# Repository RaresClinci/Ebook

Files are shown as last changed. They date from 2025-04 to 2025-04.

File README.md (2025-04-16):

# Openbook E-Reader

## Schema bloc
``` mermaid
 flowchart TB
    USB1["USB-C"] -->|5V| Charger1["Battery Charger (MCP73832)"]
    Charger1 -->|Charging| LiPo1["LiPo Battery"]
    LiPo1 --> LDO1["3V3 LDO"]
    LiPo1 --> DC5["5V DC/DC"]

    ESP1["ESP32-C3-WROOM"]

    LDO1 -->|3.3V| ESP1
    LDO1 -->|3.3V| Display1["1.5'' E-Ink Display (200x200px)"]
    LDO1 -->|3.3V| SD1["SD Card"]
    LDO1 -->|3.3V| Temp1["Temp/RH Sensor (BME680)"]
    LDO1 -->|3.3V| BatteryGauge["Battery Fuel Gauge (MAX17048)"]
    LDO1 -->|3.3V| Buttons1["Buttons (3x)"]

    ESP1 -- SPI --> Display1
    ESP1 -- SPI --> SD1
    ESP1 -- GPIO --> Buttons1
    ESP1 -- I2C --> Temp1
    ESP1 -- I2C --> BatteryGauge
    ESP1 -- I2C --> RTC["Real Time Clock (DS3231)"]
    ESP1 -- USB --> USB1

```

## Bill of Materials

Pentru componentele care se repeta, am adaugat doar la prima aparitioe datasheetul si linkul catre site.
TP-urile le-am proiectat singur, de aceea nu au o datasheet si un link catre site.

| Name of component  | Device | Check Prices | DataSheet |
|---|---|---|---|
| BOOT_BUTTON | BUTTON_CUSYOMV1 | [Check Price](https://industry.panasonic.com/global/en/products/control/switch/light-touch/number/evqpuj02k)  | [DataSheet](https://industry.panasonic.com/global/en/products/control/switch/light-touch/number/evqpuj02k) |
| C1 | ESP32_WROVER_EAGLE-LTSPICE_CC0402 | [Check Price](https://industry.panasonic.com/global/en/products/control/switch/light-touch/number/evqpuj02k)  | [DataSheet](https://industry.panasonic.com/global/en/products/control/switch/light-touch/number/evqpuj02k) |
| C1_BAT | ESP32_WROVER_EAGLE-LTSPICE_CC0402 | #N/A | #N/A |
| C1_BAT1 | EAGLE-LTSPICE_CC0402 | #N/A | #N/A |
| C1_BAT2 | EAGLE-LTSPICE_CC0402 | #N/A | #N/A |
| C2 | ESP32_WROVER_EAGLE-LTSPICE_CC0402 | #N/A | #N/A |
| C2_BAT | ESP32_WROVER_EAGLE-LTSPICE_CC0402 | #N/A | #N/A |
| C3 | RCL_CPOL-EUCT3528 | #N/A | #N/A |
| C4 | ESP32_WROVER_EAGLE-LTSPICE_CC0402 | #N/A | #N/A |
| C4_USB | ESP32_WROVER_EAGLE-LTSPICE_CC0402 | #N/A | #N/A |
| C5 | ESP32_WROVER_EAGLE-LTSPICE_CC0402 | #N/A | #N/A |
| C5_USB | ESP32_WROVER_EAGLE-LTSPICE_CC0402 | #N/A | #N/A |
| C6 | ESP32_WROVER_EAGLE-LTSPICE_CC0402 | #N/A | #N/A |
| C7 | ESP32_WROVER_EAGLE-LTSPICE_CC0402 | #N/A | #N/A |
| C8 | ESP32_WROVER_EAGLE-LTSPICE_CC0402 | #N/A | #N/A |
| C9 | EAGLE-LTSPICE_CC0402 | #N/A | #N/A |
| C10 | ESP32_WROVER_EAGLE-LTSPICE_CC0402 | #N/A | #N/A |
| C10_SUPERCAP | CPH3225A | [Check Price](https://www.snapeda.com/parts/CPH3225A/Seiko+Instruments/view-part/?ref=eda) | [DataSheet](https://www.snapeda.com/parts/CPH3225A/Seiko+Instruments/view-part/?ref=eda) |
| CHANGE_BUTTON | BUTTON_CUSYOMV1 | [Check Price](https://industry.panasonic.com/global/en/products/control/switch-light-touch/number/evqpuj02k)  | [DataSheet](https://industry.panasonic.com/global/en/products/control/switch-light-touch/number/evqpuj02k) |
| CHG_LED | ADAFRUIT_LEDCHIP-LED0603 | [Check Price](https://www.snapeda.com/parts/KP-1608SURCK/Kingbright/view-part/?ref=search&t=LED%200603) | [DataSheet](https://www.snapeda.com/parts/KP-1608SURCK/Kingbright/view-part/?ref=search&t=LED%200603) |
| C_DELAY | ESP32_WROVER_EAGLE-LTSPICE_CC0402 | #N/A | #N/A |
| D1 | USBLC6-2SC6Y | [Check Price](https://www.snapeda.com/parts/USBLC6-2SC6Y/STMicroelectronics/view-part/?ref=eda) | [DataSheet](https://www.snapeda.com/parts/USBLC6-2SC6Y/STMicroelectronics/view-part/?ref=eda) |
| D2 | ESP32_WROVER_AVX---SD0805S020S1R0_AVX_... | [Check Price](https://eu.mouser.com/ProductDetail/KYOCERA-AVX/SD0805S020S1R0?qs=jCA%252BPfw4LHbpkAoSnwrdjw%3D%3D) | [DataSheet](http://datasheets.avx.com/schottky.pdf) |
| D3 | MBR0530 | [Check Price](https://eu.mouser.com/ProductDetail/KYOCERA-AVX/SD0805S020S1R0?qs=jCA%252BPfw4LHbpkAoSnwrdjw%3D%3D) | [DataSheet](https://eu.mouser.com/ProductDetail/KYOCERA-AVX/SD0805S020S1R0?qs=jCA%252BPfw4LHbpkAoSnwrdjw%3D%3D) |
| D4 | MBR0530 | [Check Price](https://www.snapeda.com/parts/MBR0530/Onsemi/view-part/?ref=eda) | [DataSheet](https://www.snapeda.com/parts/MBR0530/Onsemi/view-part/?ref=eda) |
| D5 | MBR0530 | [Check Price](https://www.snapeda.com/parts/MBR0530/Onsemi/view-part/?ref=eda) | [DataSheet](https://www.snapeda.com/parts/MBR0530/Onsemi/view-part/?ref=eda) |
| D6 | PGB1010603MR | [Check Price](https://www.snapeda.com/parts/PGB1010603MR/Littelfuse/view-part/?ref=eda) | [DataSheet](https://www.snapeda.com/parts/PGB1010603MR/Littelfuse/view-part/?ref=eda) |
| D7 | ESP32_WROVER_AVX---SD0805S020S1R0_AVX_... | [Check Price](https://eu.mouser.com/ProductDetail/KYOCERA-AVX/SD0805S020S1R0?qs=jCA%252BPfw4LHbpkAoSnwrdjw%3D%3D) | [DataSheet](http://datasheets.avx.com/schottky.pdf) |
| D8 | PGB1010603MR | [Check Price](https://www.snapeda.com/parts/PGB1010603MR/Littelfuse/view-part/?ref=eda) | [DataSheet](https://www.snapeda.com/parts/PGB1010603MR/Littelfuse/view-part/?ref=eda) |
| D9 | PGB1010603MR | [Check Price](https://www.snapeda.com/parts/PGB1010603MR/Littelfuse/view-part/?ref=eda) | [DataSheet](https://www.snapeda.com/parts/PGB1010603MR/Littelfuse/view-part/?ref=eda) |
| D10 | PGB1010603MR | [Check Price](https://www.snapeda.com/parts/PGB1010603MR/Littelfuse/view-part/?ref=eda) | [DataSheet](https://www.snapeda.com/parts/PGB1010603MR/Littelfuse/view-part/?ref=eda) |
| D11 | PGB1010603MR | [Check Price](https://www.snapeda.com/parts/PGB1010603MR/Littelfuse/view-part/?ref=eda) | [DataSheet](https://www.snapeda.com/parts/PGB1010603MR/Littelfuse/view-part/?ref=eda) |
| D12 | PGB1010603MR | [Check Price](https://www.snapeda.com/parts/PGB1010603MR/Littelfuse/view-part/?ref=eda) | [DataSheet](https://www.snapeda.com/parts/PGB1010603MR/Littelfuse/view-part/?ref=eda) |
| EPD_C1 | ESP32_WROVER_EAGLE-LTSPICE_CC0402 | #N/A | #N/A |
| EPD_C2 | ESP32_WROVER_EAGLE-LTSPICE_CC0402 | #N/A | #N/A |
| EPD_C5 | ESP32_WROVER_EAGLE-LTSPICE_CC0402 | #N/A | #N/A |
| EPD_C6 | ESP32_WROVER_EAGLE-LTSPICE_CC0402 | #N/A | #N/A |
| EPD_C7 | ESP32_WROVER_EAGLE-LTSPICE_CC0402 | #N/A | #N/A |
| EPD_C8 | ESP32_WROVER_EAGLE-LTSPICE_CC0402 | #N/A | #N/A |
| EPD_C9 | ESP32_WROVER_EAGLE-LTSPICE_CC0402 | #N/A | #N/A |
| EPD_C10 | ESP32_WROVER_EAGLE-LTSPICE_CC0402 | #N/A | #N/A |
| EPD_C11 | ESP32_WROVER_EAGLE-LTSPICE_CC0402 | #N/A | #N/A |
| EPD_C12 | ESP32_WROVER_EAGLE-LTSPICE_CC0402 | #N/A | #N/A |
| IC1 | BD5229G-TR | [Check Price](https://componentsearchengine.com/part-view/BD5229G-TR/ROHM%20Semiconductor) | [DataSheet](https://componentsearchengine.com/part-view/BD5229G-TR/ROHM%20Semiconductor) |
| IC4 | XC6220A331MR-G | [Check Price](https://componentsearchengine.com/part-view/XC6220A331MR-G/Torex) | [DataSheet](https://componentsearchengine.com/part-view/XC6220A331MR-G/Torex) |
| J1 | FH34SRJ-24S-0.5SH_99_ | [Check Price](https://componentsearchengine.com/part-view/XC6220A331MR-G/Torex) | [DataSheet](https://componentsearchengine.com/part-view/XC6220A331MR-G/Torex) |
| J2 | SAMACSYS_PARTS_USB4110-GF-A | [Check Price](https://componentsearchengine.com/part-view/USB4110-GF-A/GCT%20(GLOBAL%20CONNECTOR%20TECHNOLOGY) | [DataSheet](https://componentsearchengine.com/part-view/USB4110-GF-A/GCT%20(GLOBAL%20CONNECTOR%20TECHNOLOGY) |
| J3 | QWIIC_CONNECTORJS-1MM | [Check Price](https://www.snapeda.com/parts/PRT-14417/SparkFun%20Electronics/view-part/?ref=search&t=qwiic%20connectpr) | [Datasheet](https://www.snapeda.com/parts/PRT-14417/SparkFun%20Electronics/view-part/?ref=search&t=qwiic%20connectpr) |
| J4 | 112A-TAAR-R03_ATTEND | [Check Price](https://store.comet.srl.ro/Catalogue/Product/43497/) | [DataSheet](https://store.comet.srl.ro/Catalogue/Product/43497/) |
| L1 | 744043680IND_4828-WE-TPC_WRE | [Check Price](https://eu.mouser.com/ProductDetail/Wurth-Elektronik/744043680?qs=PGXP4M47uW6VkZq%252BkzjrHA%3D%3D) | [DataSheet](https://eu.mouser.com/ProductDetail/Wurth-Elektronik/744043680?qs=PGXP4M47uW6VkZq%252BkzjrHA%3D%3D) |
| PFMF.050.1 | ESP32C6_VARISTORCN1812 | [Check Price](https://www.mouser.co.uk/ProductDetail/EPCOS-TDK/B72520T0350K062?qs=dEfas%2FXlABIszF52uu7vrg%3D%3D) | [DataSheet](https://www.mouser.co.uk/ProductDetail/EPCOS-TDK/B72520T0350K062?qs=dEfas%2FXlABIszF52uu7vrg%3D%3D) |
| Q1 | ESP32_WROVER_SPARKFUN-DISCRETESEMI_MOSFET_... | [Check Price](https://componentsearchengine.com/part-view/DMG2305UX-7/Diodes%20Incorporated) | [DataSheet](https://componentsearchengine.com/part-view/DMG2305UX-7/Diodes%20Incorporated) |
| Q2 | ESP32_WROVER_SPARKFUN-DISCRETESEMI_MOSFET_... | #N/A | #N/A |
| Q3 | D8 | [Check Price](https://componentsearchengine.com/part-view/PGB1010603MR/Littelfuse) | [DataSheet](https://componentsearchengine.com/part-view/PGB1010603MR/Littelfuse) |
| Q4 | Q2_TS-B2_REACHPACK | #N/A | #N/A |
| SJ1 | SJ | [Check Price](https://grabcad.com/library/solder-jumpers-1) | [DataSheet](https://grabcad.com/library/solder-jumpers-1) | |

## Descriere detaliată a funcționalității hardware

### 1. Microcontroller – ESP32-C6
Dispozitivul se bazează pe microcontroller-ul**ESP32-C6-WROOM-1**, bazat pe un nucleu **RISC-V pe 32 de biți**, cu frecvențe de lucru de până la **160 MHz**.

- **Memorie**: 512 KB de SRAM intern și **8 MB flash extern** (W25Q512JVEIQ).
- **Conectivitate**: Wi-Fi 6, Bluetooth 5 LE, USB 2.0
- **Periferice**: suport pentru SPI, I²C, UART și multiple GPIO-uri.
- **Moduri de consum redus**: suportă sleep și deep sleep, ideale pentru dispozitive portabile alimentate cu baterie.

### 2. Afișaj E-Ink
**E-Ink de 7.5" (800x480px)** – Waveshare (sau echivalent) cu rezoluție 800×480

**Interfață**: 4-wire SPI + pini de control (CS, DC, RST, BUSY).  
**Consum**: extrem de redus în regim static; doar în timpul reîmprospătării imaginea consumul crește la ~15–25mA.

 **Avantaj**: Afișajele E-Ink păstrează imaginea fără consum de curent, ceea ce le face perfecte pentru aplicații de tip e-reader.

### 3. Senzor de Mediu – BME680
Senzorul integrează măsurători de **temperatură**, **umiditate**, **presiune atmosferică** și **calitate a aerului (VOC/eCO₂)**.

- **Interfață**: I²C la 400 kHz.
- **Consum**: ~2.1µA în standby, până la câțiva mA în timpul citirilor.

 **BME680** este o alegere excelenta datorita capacitatii sale de a integra multiple tipuri de masuratori intr-un singur cip

### 4. Managementul energiei
- **Baterie Li-Po 3.7V, 2500mAh** – oferă autonomie extinsă.
- **Circuit de încărcare**: MCP73831, conectat la USB-C, permite încărcare cu până la **1A**.
- **Fuel Gauge**: MAX17048 – monitorizează starea bateriei prin I²C (tensiune, încărcare, alertă descărcare).
- **LDO**: XC6220A331MR-G – asigură **tensiune stabilă de 3.3V** pentru toate componentele critice.

### 5. Interacțiune – Butoane (3x)
Dispozitivul include **trei butoane tactile** pentru navigare, selectare și întoarcere pagină. Fiecare este conectat la un GPIO și poate avea debouncing hardware (rezistor + condensator) sau software, pentru evitarea semnalelor false.

### 6. Port USB-C
- **Roluri**: încărcarea bateriei, transfer de date (USB 2.0), și update de firmware (via bootloader sau OTA).
- **Protecție**: ESD (ex: USBLC6-2SC6Y), rezistențe de terminare conforme cu specificațiile USB-C.

### 7. Conector Qwiic (I²C)
Conector standard cu 4 pini (VCC, GND, SDA, SCL) pentru atașarea rapidă a senzorilor/modulor I²C, ideal în extensii și prototipare.

### 8. Card MicroSD(112A-TAAR-R03)
- **Conector dedicat**: pentru log-uri, e-book-uri sau update-uri firmware.
- **Interfață**: Poate fi SD (1-bit / 4-bit) sau SPI, în funcție de configurația firmware-ului.

### 9. Ceas de timp real – RTC DS3231
- **Precizie ridicată**.
- **Backup**: cu baterie sau supercondensator.
- **Comunicare**: I²C, împreună cu ceilalți senzori.

### 10. Memorie Flash externă – W25Q512JVEIQ
- **Interfață**: quad SPI – pentru încărcare rapidă de date și firmware.
- Utilizată pentru stocarea aplicațiilor, imaginilor sau fișierelor mari (ex: e-book-uri).

---

### Interfețele utilizate

| Interfață | Componente conectate |
|---|---|
| **SPI**  | Afișaj E-Ink, memorie flash externă, card SD |
| **I²C**  | BME680, MAX17048 (fuel gauge), RTC DS3231, conector Qwiic |
| **GPIO** | Butoane, control display (RST, BUSY etc.) |
| **USB**  | Alimentare și date (USB-C) |

---

### Estimare consum energetic

| Componentă | Consum tipic |
|---|---|
| ESP32 (activ) | ~80 mA (Wi-Fi) / <10 mA (idle) |
| E-Ink (refresh) | ~15–25 mA |
| BME680 | ~3.6 mA (peak) / 2.1 µA (sleep)  |
| MAX17048 (Fuel Gauge) | ~50 µA |
| DS3231 (RTC) | ~3.5 mA (activ) / <1 µA (backup) |
| Total (deep sleep) | ~50–100 µA |
| Total (activ cu Wi-Fi)  | ~100–150 mA |

> Cu o baterie de **2500mAh**, în regim normal de utilizare (afișaj static, deep sleep majoritatea timpului), autonomia poate atinge **câteva săptămâni**.

## Alocarea pinilor pentru ESP32-C6

| Pin ESP32-C6  | Componentă / Semnal | Descriere |
|---|---|---|
| GPIO1 | I²C SDA (BME680, MAX17048, DS3231, Qwiic) | Linie de date partajată pentru toți senzorii(+ RTC) conectați pe magistrala I²C. |
| GPIO2 | I²C SCL (BME680, MAX17048, DS3231, Qwiic) | Linie de clock pentru sincronizarea comunicației I²C. |
| GPIO5 | SPI MISO (E-Paper) | Recepție date de la afișajul E-Paper. |
| GPIO6 | SPI MOSI (E-Paper) | Transmitere date către afișajul E-Paper. |
| GPIO7 | SPI CLK (E-Paper) | Semnal de clock pentru interfața SPI a ecranului.  |
| GPIO8 | SPI CS (E-Paper) | Chip Select pentru e-paper. |
| GPIO9 | E-Paper DC (Data/Command) | Selectează între transmiterea de date sau comenzi către afișaj. |
| GPIO10 | E-Paper RST | Reset hardware al afișajului. |
| GPIO11 | E-Paper BUSY | Indică dacă afișajul este ocupat cu o operație. |
| GPIO12 | Button #1 | Buton de control (ex. „Pagina următoare”). |
| GPIO13 | Button #2 | Buton de control (ex. „Pagina anterioară”). |
| GPIO14 | Button #3 | Buton de control (ex. „Meniu” sau „Select”). |
| GPIO15 | MAX17048 ALERT (opțional) | Semnal de alertă de la senzorul de baterie (low battery). |
| GPIO16 | USB D+ (intern la USB PHY) | Semnal diferențial pozitiv pentru conexiunea USB 2.0. |
| GPIO17 | USB D- (intern la USB PHY) | Semnal diferențial negativ pentru conexiunea USB 2.0. |
| GPIO18 | LED de status (opțional) | LED pentru semnalizare stări (Wi-Fi, încărcare etc.). |
| GPIO19 | SD Card CS (opțional) | Chip Select pentru cardul microSD (SPI). |
| GPIO20 | SD Card MISO (opțional) | Linie de citire date de la cardul microSD. |
| GPIO21 | SD Card MOSI (opțional) | Linie de scriere date către cardul microSD. |
| GPIO4 | SD Card CLK (opțional) | Linie de clock pentru comunicația SPI cu cardul SD.|

## Note
- am adaugat la partea de PCB 2D niste masuratori in plus pentru claritate
- am pozitionat TP-urile in cel mai apropiat loc de componentele conectate
- am mai adaugat pe placa o zona unde poate fi scris numarul de serie al placii si versiunea ei(probabil va deveni Openbook v1.2 dupa feedback - UPDATE: chiar a devenit)
- pentru baterie, am folosit un paralelipiped cu dimensiunile maxime din datasheet
- la partea de PCB, am aprobat 2 erori de gauri de la o componenta si o eroare de Airwire la componenta J4, are 9 grounduri puse intr-un grid 3x3 si cel din mijloc nu e accesibil

## Concluzii
A fost un proiect destul de solicitant, dar cu multa munca am reusit sa il duc pana la capat. Am luat in considerare majoritatea indicatiilor si sunt deschis sa fac imbunatatiri pe urma feedbackului.

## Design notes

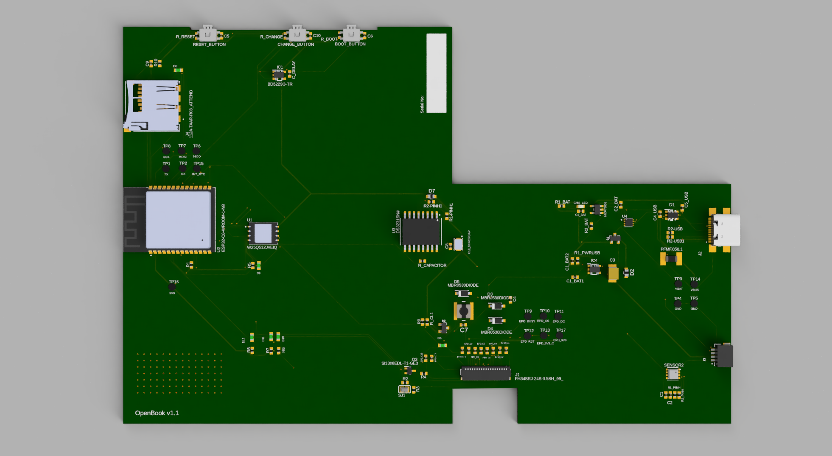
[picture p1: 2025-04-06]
Images/PCB_Openbook_3D_2025-Apr-06_12-04-20PM-000_CustomizedView25513308225.png

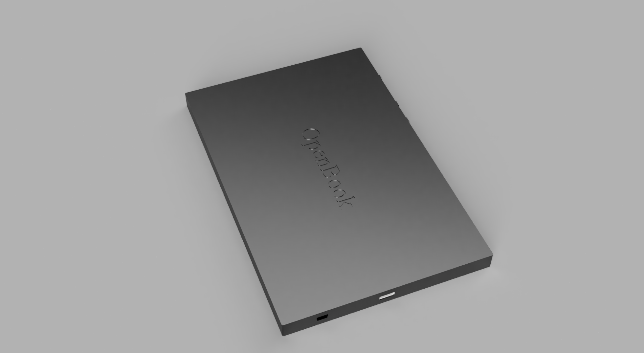
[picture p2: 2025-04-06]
Images/OpenBook_Enclosure_2025-Apr-06_12-09-38PM-000_CustomizedView32989049205.png

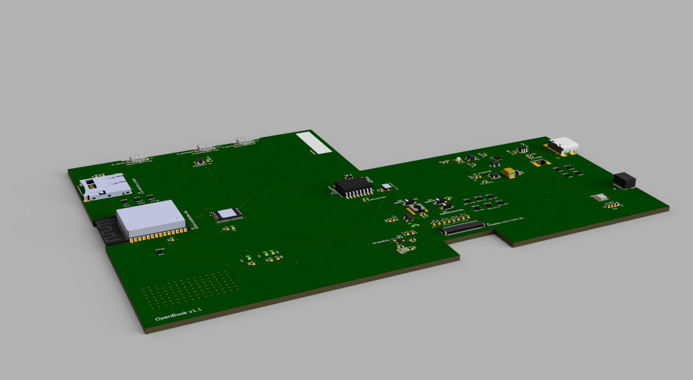
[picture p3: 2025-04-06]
Images/PCB_Openbook_3D_2025-Apr-06_12-02-53PM-000_CustomizedView3641258684.png

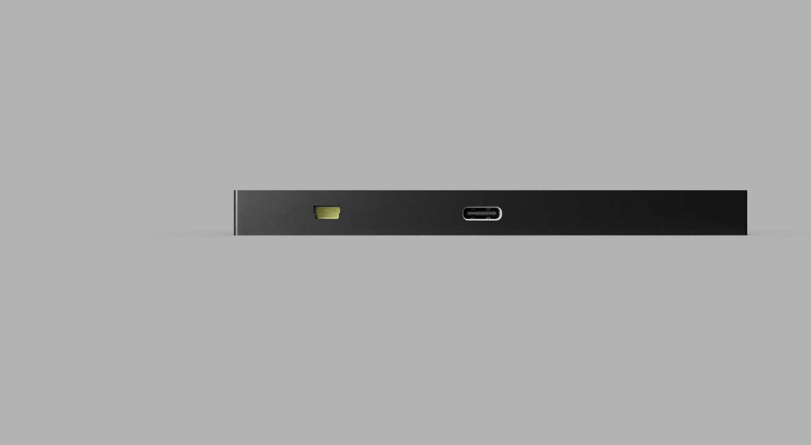
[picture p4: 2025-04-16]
Images/OpenBook_Enclosure_2025-Apr-16_10-03-07AM-000_CustomizedView7075589105.png

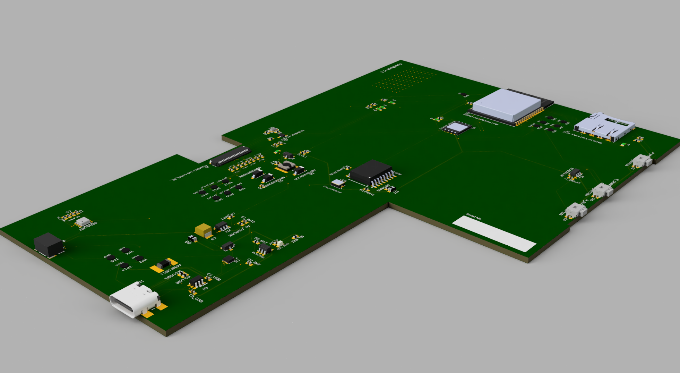
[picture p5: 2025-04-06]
Images/PCB_Openbook_3D_2025-Apr-06_12-05-02PM-000_CustomizedView13622716074.png

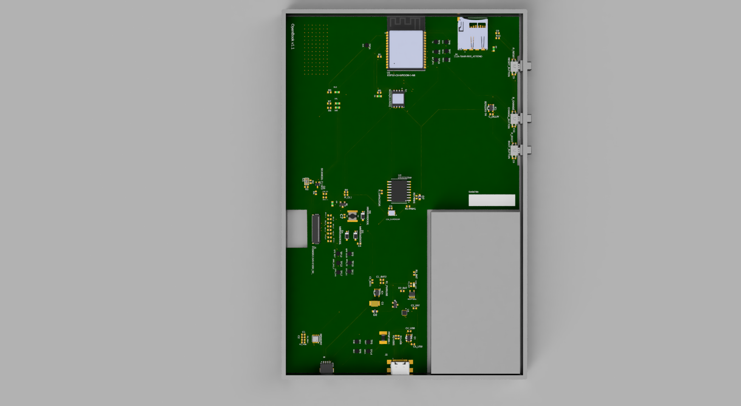
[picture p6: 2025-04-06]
Images/b6aed16a-0078-495b-a1fc-863c3d2823d8.PNG

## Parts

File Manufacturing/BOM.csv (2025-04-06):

Qty | Value | Device | Package | Parts | Description | ARROW_PART_NUMBER | ARROW_PRICE-STOCK | AVAILABILITY | CENTROID_NOT_SPECIFIED | CHECK_PRICES | COPYRIGHT | DATASHEET | DESCRIPTION | DIGIKEY_DESCRIPTION | DIGIKEY_PART_NUMBER | HEIGHT | LEAD_FREE | MANUFACTURER_NAME | MANUFACTURER_PART_NUMBER | MF | MFR_NAME | MOUSER_PART_NUMBER | MOUSER_PRICE-STOCK | MOUSER_TESTING_PART_NUMBER | MOUSER_TESTING_PRICE-STOCK | MP | MPN | PACKAGE | POPULARITY | PREFIX | PRICE | PROD_ID | PURCHASE-URL | ROHS | SNAPEDA_LINK | SPICEPREFIX | TEMPERATURE_RANGE_HIGH | TEMPERATURE_RANGE_LOW | VALUE
1 |  | ADAFRUIT_LEDCHIP-LED0603 | ADAFRUIT_CHIP-LED0603 | CHG_LED | LED
1 |  | SJ | SJ | SJ1 | SMD solder JUMPER |  |  |  |  |  |  |  |  |  |  |  |  |  |  |  |  |  |  |  |  |  |  |  | 3
1 | 0.1uF/50V | ESP32_WROVER_EAGLE-LTSPICE_CC0402 | EAGLE-LTSPICE_C0402 | EPD_C5 | CAPACITOR, European symbol
1 | 0.47 | ESP32_WROVER_EAGLE-LTSPICE_RR0402 | ESP32_WROVER_EAGLE-LTSPICE_R0402 | R3 | RESISTOR, European symbol
1 | 100K | ESP32_WROVER_EAGLE-LTSPICE_RR0402 | ESP32_WROVER_EAGLE-LTSPICE_R0402 | R1_PWRUSB | RESISTOR, European symbol
8 | 100nF | ESP32_WROVER_EAGLE-LTSPICE_CC0402 | EAGLE-LTSPICE_C0402 | C1, C2, C4_USB, C6, C8, C9, C10, C_DELAY | CAPACITOR, European symbol
1 | 100uF TANT | RCL_CPOL-EUCT3528 | RCL_CT3528 | C3 | POLARIZED CAPACITOR, European symbol |  |  |  |  |  |  |  |  |  |  |  |  |  |  |  |  |  |  |  |  |  |  |  | 0 |  |  |  |  |  |  | C
16 | 10K | ESP32_WROVER_EAGLE-LTSPICE_RR0402 | ESP32_WROVER_EAGLE-LTSPICE_R0402 | R1, R1-PINH1, R1_PINH, R2-PINH1, R2_PINH, R4, R5, R6, R7, R8, R9, R10, R_BOOT, R_CHANGE, R_CL1, R_RESET | RESISTOR, European symbol
1 | 10uF | ESP32_WROVER_EAGLE-LTSPICE_CC0402 | EAGLE-LTSPICE_C0402 | C7 | CAPACITOR, European symbol
1 | 112A-TAAR-R03_ATTEND | 112A-TAAR-R03_ATTEND | 112ATAARR03ATTEND | J4 | Micro SD Card Socket, Push-Push Type, Top Mount, SMT, H=1.83mm, 10u |  |  |  |  |  |  |  | Micro SD Card Socket | Push-Push Type | Top Mount | SMT | H=1.83mm | 10u |  |  | 1.9mm |  | ATTEND | 112A-TAAR-R03 ATTEND
1 | 15 | ESP32_WROVER_EAGLE-LTSPICE_RR0402 | ESP32_WROVER_EAGLE-LTSPICE_R0402 | R_CAPACITOR | RESISTOR, European symbol
1 | 1uF | ESP32_WROVER_EAGLE-LTSPICE_CC0402 | EAGLE-LTSPICE_C0402 | C5 | CAPACITOR, European symbol
9 | 1uF/50V | ESP32_WROVER_EAGLE-LTSPICE_CC0402 | EAGLE-LTSPICE_C0402 | EPD_C1, EPD_C2, EPD_C6, EPD_C7, EPD_C8, EPD_C9, EPD_C10, EPD_C11, EPD_C12 | CAPACITOR, European symbol
1 | 2.2 | ESP32_WROVER_EAGLE-LTSPICE_RR0402 | ESP32_WROVER_EAGLE-LTSPICE_R0402 | R2 | RESISTOR, European symbol
1 | 200 | ESP32_WROVER_EAGLE-LTSPICE_RR0402 | ESP32_WROVER_EAGLE-LTSPICE_R0402 | R1_BAT | RESISTOR, European symbol
2 | 20V/4.2A/52mO/1.4W | ESP32_WROVER_SPARKFUN-DISCRETESEMI_MOSFET_PCH-DMG2305UX-7 | ESP32_WROVER_SPARKFUN-DISCRETESEMI_SOT23-3 | Q1, Q2 | P-channel MOSFETs
1 | 2K | ESP32_WROVER_EAGLE-LTSPICE_RR0402 | ESP32_WROVER_EAGLE-LTSPICE_R0402 | R2_BAT | RESISTOR, European symbol
5 | 4.7uF | ESP32_WROVER_EAGLE-LTSPICE_CC0402 | EAGLE-LTSPICE_C0402 | C1_BAT, C1_BAT1, C1_BAT2, C2_BAT, C5_USB | CAPACITOR, European symbol
1 | 4.7uF/25V | ESP32_WROVER_EAGLE-LTSPICE_CC0402 | EAGLE-LTSPICE_C0402 | C4 | CAPACITOR, European symbol
2 | 5k1 | ESP32_WROVER_EAGLE-LTSPICE_RR0402 | ESP32_WROVER_EAGLE-LTSPICE_R0402 | R2-USB, R2-USB1 | RESISTOR, European symbol
1 | 68uH | 744043680IND_4828-WE-TPC_WRE | IND_4828-WE-TPC_WRE | L1 |  |  |  |  |  |  | Copyright (C) 2024 Ultra Librarian. All rights reserved. |  |  |  |  |  |  |  | 744043680 |  | Wurth Electronics
1 | BD5229G-TR | BD5229G-TR | SOT95P280X125-5N | IC1 | Voltage Detector with Adjustable Delay Time: CMOS processes are utilized to develop high precision, low current consumption CMOS reset ICs that allow arbitrary setting of the delay time. The extensive lineup includes both Nch Open Drain and CMOS output types in a wide range of detection voltages (from 2.3V to 6.0V, in 0.1V steps), enabling selection of the ideal solution based on customer requirements. In addition, the entire series is of course both lead-free and RoHS-compliant. |  |  |  |  |  |  |  | Voltage Detector with Adjustable Delay Time: CMOS processes are utilized to develop high precision | low current consumption CMOS reset ICs that allow arbitrary setting of the delay time. The extensive lineup includes both Nch Open Drain and CMOS output types in a wide range of detection voltages (from 2.3V to 6.0V | in 0.1V steps) | enabling selection of the ideal solution based on customer requirements. In addition | the entire series is of course both lead-free and RoHS-compliant. |  |  | 1.25mm |  | ROHM Semiconductor | BD5229G-TR |  |  | 755-BD5229G-TR | https://www.mouser.co.uk/ProductDetail/ROHM-Semiconductor/BD5229G-TR?qs=4kLU8WoGk0vvnhrrYwdszw%3D%3D
1 | BME688 | ESP32_WROVER_BME680_BME680 | ESP32_WROVER_BME680_PSON80P300X300X100-8N | SENSOR2 | Integrated Environmental Unit |  |  | Unavailable |  |  |  |  | Integrated Environmental Unit |  |  |  |  |  |  | Bosch Sensortec |  |  |  |  |  | BME680 |  | LGA-8 Bosch Tools |  |  | None
3 | BUTTON_CUSYOMV1BUTTON | BUTTON_CUSYOMV1BUTTON | MYBUTTON | BOOT_BUTTON, CHANGE_BUTTON, RESET_BUTTON
1 | CPH3225A | CPH3225A | CAPCP3225X100N | C10_SUPERCAP | Cap 0.011F 3.3V 1210 Flat Check availability |  |  | Not in stock |  | https://www.snapeda.com/parts/CPH3225A/Seiko+Instruments/view-part/?ref=eda |  |  | 11 mF (EDLC) Supercapacitor 3.3 V 1210 (3225 Metric) - - |  |  |  |  |  |  | Seiko Instruments |  |  |  |  |  | CPH3225A |  | 1210 Seiko |  |  | None |  | https://www.snapeda.com/api/url_track_click_mouser/?unipart_id=562593&manufacturer=Seiko Instruments&part_name=CPH3225A&search_term=None |  | https://www.snapeda.com/parts/CPH3225A/Seiko+Instruments/view-part/?ref=snap
1 | DS3231SN# | DS3231SN# | SOIC127P1032X265-16N | U3 | Real Time Clock Serial 16-Pin SOIC W T/R Check availability |  |  | In Stock |  | https://www.snapeda.com/parts/DS3231SN%23/Analog+Devices/view-part/?ref=eda |  |  | Extremely Accurate I²C-Integrated RTC/TCXO/Crystal |  |  |  |  |  |  | Analog Devices |  |  |  |  |  | DS3231SN# |  | SOIC-16 Maxim |  |  | None |  | https://www.snapeda.com/api/url_track_click_mouser/?unipart_id=99048&manufacturer=Analog Devices&part_name=DS3231SN#&search_term=None |  | https://www.snapeda.com/parts/DS3231SN%23/Analog+Devices/view-part/?ref=snap
1 | ESP32-C6-WROOM-1-N8 | ESP32-C6-WROOM-1-N8 | XCVR_ESP32-C6-WROOM-1-N8 | U2 | Check availability |  |  | In Stock |  | https://www.snapeda.com/parts/ESP32-C6-WROOM-1-N8/Espressif+Systems/view-part/?ref=eda |  |  | Multiprotocol Modules ESP32-C6 module | Wi-Fi 6 in 2.4 GHz band | Bluetooth 5 | Zigbee 3.0 and Thread. ESP34-WROOM Compatible - ENGINEERING SAMPLE |  |  |  |  |  |  | Espressif Systems |  |  |  |  |  | ESP32-C6-WROOM-1-N8 |  | None |  |  | None |  |  |  | https://www.snapeda.com/parts/ESP32-C6-WROOM-1-N8/Espressif+Systems/view-part/?ref=snap
1 | ESP32C6_VARISTORCN1812 | ESP32C6_VARISTORCN1812 | ESP32C6_VARISTOR_CT/CN1812 | PFMF.050.1 | VARISTOR |  |  |  |  |  |  |  |  |  |  |  |  |  |  |  |  |  |  |  |  |  |  |  | 0
1 | ESP32_WROVER_SPARKFUN-IC-POWER_MCP73831 | ESP32_WROVER_SPARKFUN-IC-POWER_MCP73831 | ESP32_WROVER_SPARKFUN-IC-POWER_SOT23-5 | MCP73831 | MCP73831T Li-Ion, Li-Pol Controller |  |  |  |  |  |  |  |  |  |  |  |  |  |  |  |  |  |  |  |  |  |  |  |  |  |  | IC-09995
1 | FH34SRJ-24S-0.5SH_99_ | FH34SRJ-24S-0.5SH_99_ | FH34SRJ24S05SH99 | J1 | (0.50mm) Surface Mount, Right Angle |  |  |  |  |  |  |  | 24 Position FFC | FPC Connector Contacts | (0.50mm) Surface Mount | Right Angle |  |  | 1.1mm |  | Hirose | FH34SRJ-24S-0.5SH(99) |  |  | 798-FH34SRJ24S05SH99 | https://www.mouser.co.uk/ProductDetail/Hirose-Connector/FH34SRJ-24S-0.5SH99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
1 | MAX17048G+T10 | MAX17048G+T10 | SON50P200X200X80-9N | U4 | Check availability |  |  | In Stock |  | https://www.snapeda.com/parts/MAX17048G+T10/Analog+Devices/view-part/?ref=eda |  |  | 3µA 1-Cell/2-Cell Fuel Gauge with ModelGauge |  |  |  |  |  |  | Analog Devices |  |  |  |  |  | MAX17048G+T10 |  | TDFN-8 Maxim |  |  | None |  | https://www.snapeda.com/api/url_track_click_mouser/?unipart_id=329239&manufacturer=Analog Devices&part_name=MAX17048G+T10&search_term=None |  | https://www.snapeda.com/parts/MAX17048G+T10/Analog+Devices/view-part/?ref=snap
3 | MBR0530DIODE | MBR0530DIODE | SOD3716X135N | D3, D4, D5 | ON SEMICONDUCTOR - MBR0530 - DIODE, SCHOTTKY, 0.5A, 30V, SOD-123
6 | PGB1010603MRDIODE | PGB1010603MRDIODE | DIOC1608X36N | D6, D8, D9, D10, D11, D12 | Check availability
1 | QWIIC_RIGHT_ANGLE | QWIIC_CONNECTORJS-1MM | JST04_1MM_RA | J3 | SparkFun I2C Standard Qwiic Connector |  |  |  |  |  |  |  |  |  |  |  |  |  |  |  |  |  |  |  |  |  |  |  |  |  |  | CONN-13694 |  |  |  |  |  |  | QWIIC_RIGHT_ANGLE
1 | SAMACSYS_PARTS_USB4110-GF-A | SAMACSYS_PARTS_USB4110-GF-A | SAMACSYS_PARTS_USB4110GFA | J2 | CONN USB 2.0 TYPE-C R/A SMT |  |  |  |  |  |  |  | CONN USB 2.0 TYPE-C R/A SMT |  |  | 3.26mm |  | GCT (GLOBAL CONNECTOR TECHNOLOGY) | USB4110-GF-A |  |  | 640-USB4110-GF-A | https://www.mouser.co.uk/ProductDetail/GCT/USB4110-GF-A?qs=KUoIvG%2F9IlYiZvIXQjyJeA%3D%3D
2 | SD0805S020S1R0 | ESP32_WROVER_AVX---SD0805S020S1R0_AVX_SD0805S020S1R0_0_0AVX_SD0805S020S1R0_0_0 | ESP32_WROVER_AVX---SD0805S020S1R0_AVX_SD0805S020S1R0_0 | D2, D7 | Schottky Barrier Rectifier Diode |  |  |  | No |  |  | http://datasheets.avx.com/schottky.pdf |  | DIODE SCHOTTKY 20V 1A 0805 | 478-7800-1-ND |  | yes |  |  | AVX |  | 581-SD0805S020S1R0 |  |  |  |  |  | 0805 (2012 metric) |  | D |  |  |  | yes |  |  | +125°C | -55°C
1 | SI1308EDL-T1-GE3 | SI1308EDL-T1-GE3 | SOT65P210X110-3N | Q3 | MOSFET N-Ch 30V 1.5A TrenchFET SC70 Vishay Si1308EDL-T1-GE3 N-channel MOSFET Transistor, 1.5 A, 30 V, 3-Pin SC-70 |  |  | In Stock |  | https://www.snapeda.com/parts/SI1308EDL-T1-GE3/Vishay+Siliconix/view-part/?ref=eda |  |  | Si1308EDL-T1-GE3 N-channel MOSFET Transistor | 1.5 A | 30 V | 3-Pin SC-70 | Siliconix / Vishay SI1308EDL-T1-GE3 |  |  |  |  |  |  | Vishay Siliconix |  |  |  |  |  | SI1308EDL-T1-GE3 |  | SOT-323 Vishay Semiconductor |  |  | None |  | https://www.snapeda.com/api/url_track_click_mouser/?unipart_id=274603&manufacturer=Vishay Siliconix&part_name=SI1308EDL-T1-GE3&search_term=None |  | https://www.snapeda.com/parts/SI1308EDL-T1-GE3/Vishay+Siliconix/view-part/?ref=snap
17 | TPTP20R | TPTP20R | TP20R | TP1, TP2, TP3, TP4, TP5, TP6, TP7, TP8, TP9, TP10, TP11, TP12, TP13, TP14, TP15, TP16, TP17 | Test pad
1 | USBLC6-2SC6Y | USBLC6-2SC6Y | SOT95P280X145-6N | D1 | Low Cap. ESD Protection Auto SOT-23-6 STMicroelectronics USBLC6-2SC6Y, Dual Uni-Directional TVS Diode Array, 6-Pin SOT-23 |  |  | In Stock |  | https://www.snapeda.com/parts/USBLC6-2SC6Y/STMicroelectronics/view-part/?ref=eda |  |  | 17V Clamp 5A (8/20µs) Ipp Tvs Diode Surface Mount SOT-23-6 |  |  |  |  |  |  | STMicroelectronics |  |  |  |  |  | USBLC6-2SC6Y |  | SOT-23-6 STMicroelectronics |  |  | None |  |  |  | https://www.snapeda.com/parts/USBLC6-2SC6Y/STMicroelectronics/view-part/?ref=snap
1 | W25Q512JVEIQ | W25Q512JVEIQ | SON127P600X800X80-9N | U1 | Check availability |  |  | In Stock |  | https://www.snapeda.com/parts/W25Q512JVEIQ/Winbond+Electronics/view-part/?ref=eda |  |  | FLASH - NOR Memory IC 512Mb (64M x 8) SPI - Quad I/O 133 MHz 8-WSON (8x6) |  |  |  |  |  |  | Winbond Electronics |  |  |  |  |  | W25Q512JVEIQ |  | Package |  |  | None |  |  |  | https://www.snapeda.com/parts/W25Q512JVEIQ/Winbond+Electronics/view-part/?ref=snap
1 | XC6220A331MR-G | XC6220A331MR-G | SOT95P280X120-5N | IC4 | LDO Voltage Regulators |  |  |  |  |  |  |  | LDO Voltage Regulators |  |  | 1.2mm |  | Torex | XC6220A331MR-G |  |  | 865-XC6220A331MR-G | https://www.mouser.co.uk/ProductDetail/Torex-Semiconductor/XC6220A331MR-G?qs=AsjdqWjXhJ8ZSWznL1J0gg%3D%3D

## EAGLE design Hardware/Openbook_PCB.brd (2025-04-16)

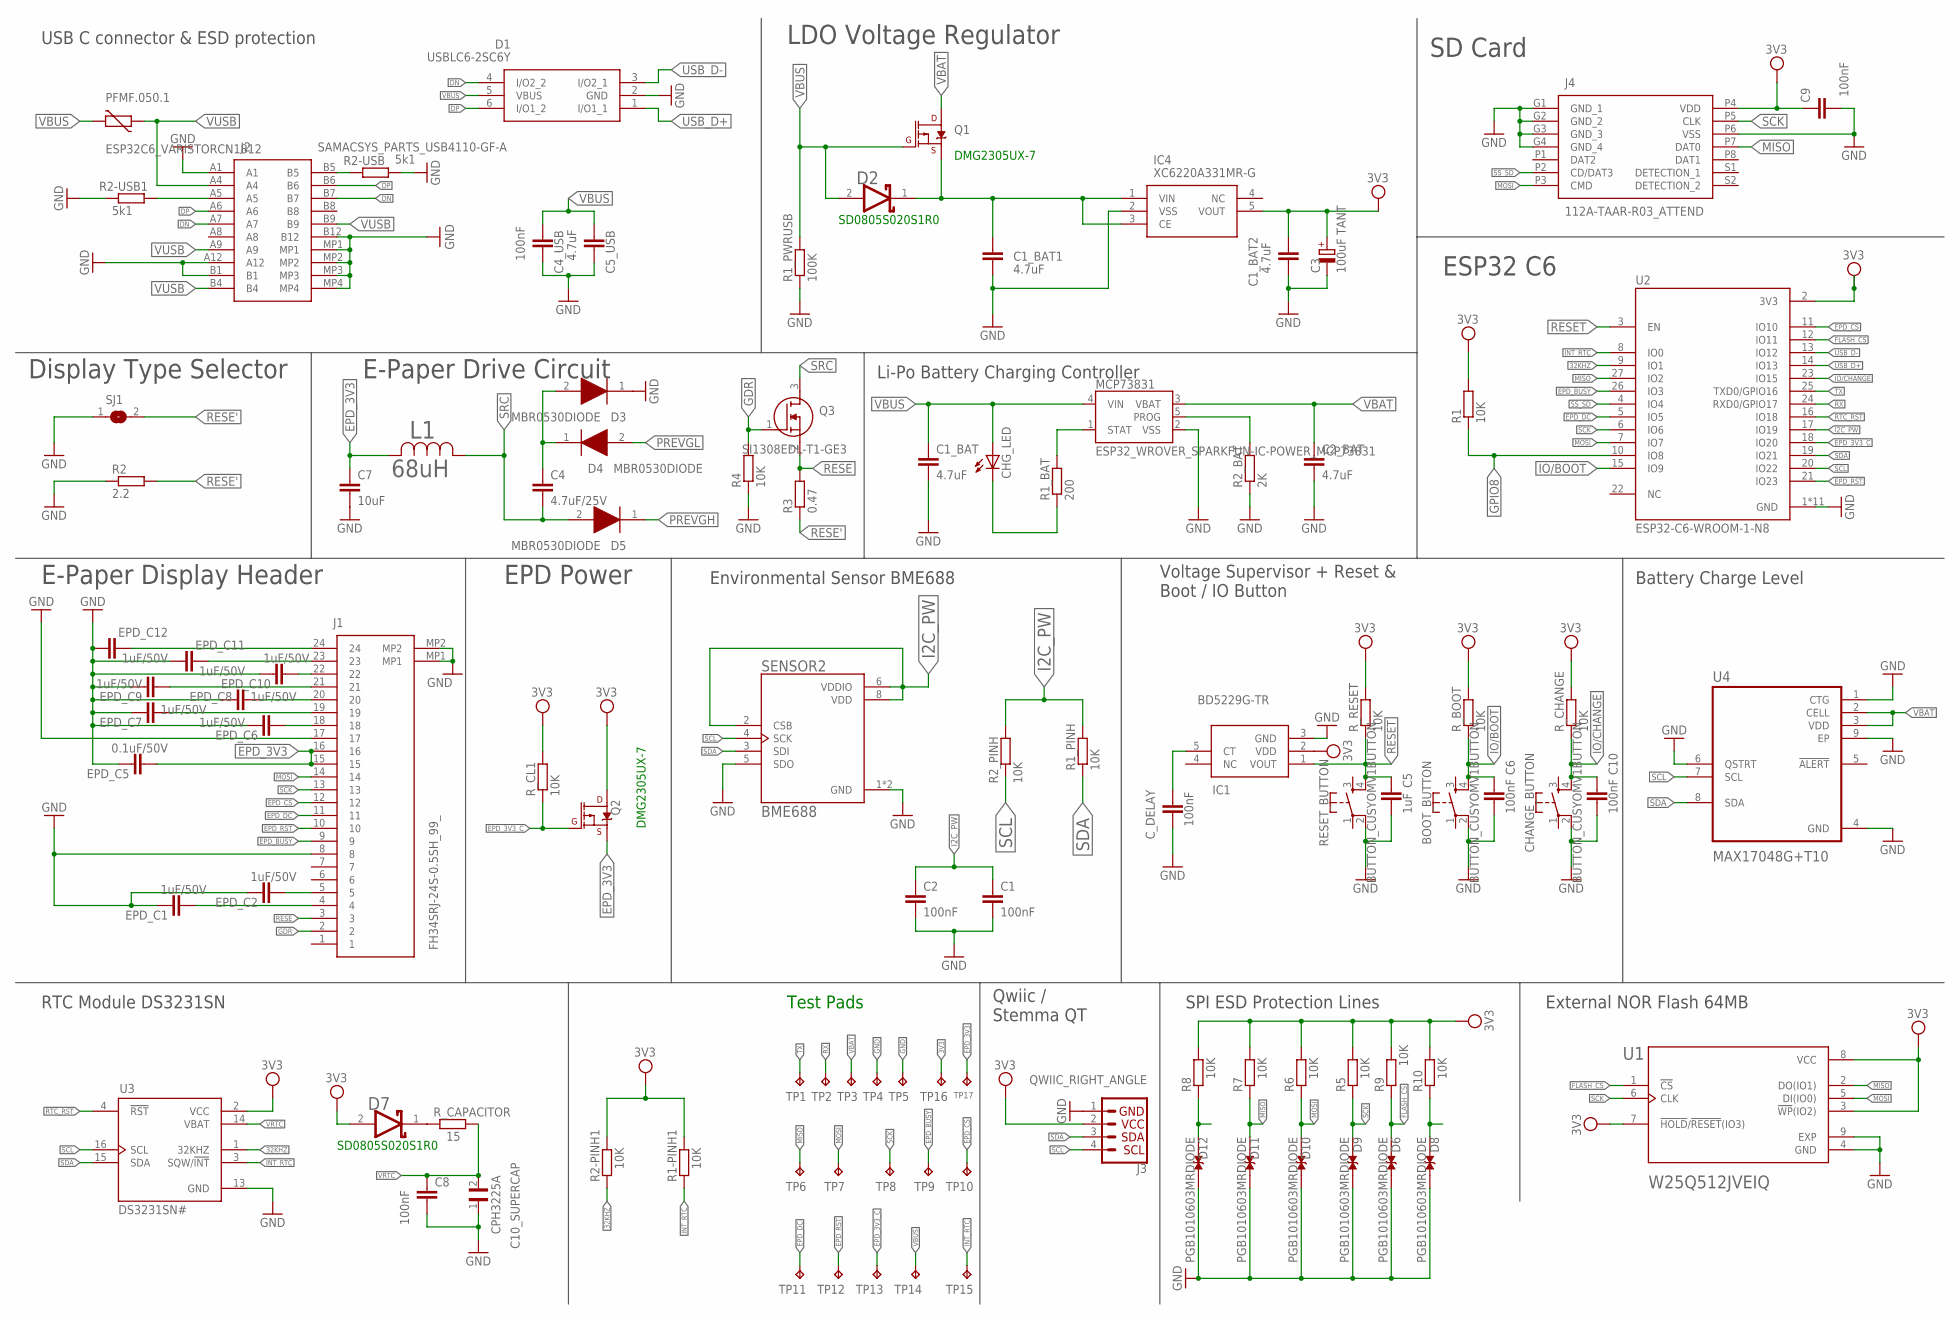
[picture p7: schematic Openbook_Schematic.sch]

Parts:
BOOT_BUTTON: BUTTON_CUSYOMV1BUTTON; MYBUTTON
C1, C2, C4_USB, C6, C8, C9, C10: 100nF; EAGLE-LTSPICE_C0402
C1_BAT, C1_BAT1, C1_BAT2, C2_BAT, C5_USB: 4.7uF; EAGLE-LTSPICE_C0402
C3: 100uF TANT; RCL_CT3528
C4: 4.7uF/25V; EAGLE-LTSPICE_C0402
C5: 1uF; EAGLE-LTSPICE_C0402
C7: 10uF; EAGLE-LTSPICE_C0402
C10_SUPERCAP: CPH3225A; CAPCP3225X100N
CHANGE_BUTTON: BUTTON_CUSYOMV1BUTTON; MYBUTTON
CHG_LED: ADAFRUIT_LEDCHIP-LED0603; ADAFRUIT_CHIP-LED0603
C_DELAY: 100nF; EAGLE-LTSPICE_C0402
D1: USBLC6-2SC6Y; SOT95P280X145-6N
D2, D7: SD0805S020S1R0; ESP32_WROVER_AVX---SD0805S020S1R0_AVX_SD0805S020S1R0_0
D3, D4, D5: MBR0530DIODE; SOD3716X135N
D6, D8, D9, D10, D11, D12: PGB1010603MRDIODE; DIOC1608X36N
EPD_C1, EPD_C2, EPD_C6, EPD_C7, EPD_C8, EPD_C9, EPD_C10, EPD_C11, EPD_C12: 1uF/50V; EAGLE-LTSPICE_C0402
EPD_C5: 0.1uF/50V; EAGLE-LTSPICE_C0402
IC1: BD5229G-TR; SOT95P280X125-5N
IC4: XC6220A331MR-G; SOT95P280X120-5N
J1: FH34SRJ-24S-0.5SH_99_; FH34SRJ24S05SH99
J2: SAMACSYS_PARTS_USB4110-GF-A; SAMACSYS_PARTS_USB4110GFA
J3: QWIIC_RIGHT_ANGLE; JST04_1MM_RA
J4: 112A-TAAR-R03_ATTEND; 112ATAARR03ATTEND
L1: 68uH; IND_4828-WE-TPC_WRE
MCP73831: ESP32_WROVER_SPARKFUN-IC-POWER_MCP73831; ESP32_WROVER_SPARKFUN-IC-POWER_SOT23-5
PFMF.050.1: ESP32C6_VARISTORCN1812; ESP32C6_VARISTOR_CT/CN1812
Q1, Q2: 20V/4.2A/52mΩ/1.4W; ESP32_WROVER_SPARKFUN-DISCRETESEMI_SOT23-3
Q3: SI1308EDL-T1-GE3; SOT65P210X110-3N
R1, R1-PINH1, R1_PINH, R2-PINH1, R2_PINH, R4, R5, R6, R7, R8, R9, R10: 10K; ESP32_WROVER_EAGLE-LTSPICE_R0402
R1_BAT: 200; ESP32_WROVER_EAGLE-LTSPICE_R0402
R1_PWRUSB: 100K; ESP32_WROVER_EAGLE-LTSPICE_R0402
R2: 2.2; ESP32_WROVER_EAGLE-LTSPICE_R0402
R2-USB, R2-USB1: 5k1; ESP32_WROVER_EAGLE-LTSPICE_R0402
R2_BAT: 2K; ESP32_WROVER_EAGLE-LTSPICE_R0402
R3: 0.47; ESP32_WROVER_EAGLE-LTSPICE_R0402
RESET_BUTTON: BUTTON_CUSYOMV1BUTTON; MYBUTTON
R_BOOT: 10K; ESP32_WROVER_EAGLE-LTSPICE_R0402
R_CAPACITOR: 15; ESP32_WROVER_EAGLE-LTSPICE_R0402
R_CHANGE: 10K; ESP32_WROVER_EAGLE-LTSPICE_R0402
R_CL1: 10K; ESP32_WROVER_EAGLE-LTSPICE_R0402
R_RESET: 10K; ESP32_WROVER_EAGLE-LTSPICE_R0402
SENSOR2: BME688; ESP32_WROVER_BME680_PSON80P300X300X100-8N
SJ1: SJ
TP1, TP2, TP3, TP4, TP5, TP6, TP7, TP8, TP9, TP10, TP11, TP12, TP13, TP14, TP15, TP16, TP17: TPTP20R; TP20R
U1: W25Q512JVEIQ; SON127P600X800X80-9N
U2: ESP32-C6-WROOM-1-N8; XCVR_ESP32-C6-WROOM-1-N8
U3: DS3231SN#; SOIC127P1032X265-16N
U4: MAX17048G+T10; SON50P200X200X80-9N

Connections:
3V3: C1_BAT2.1, C3.+, C9.1, D7.2 (ANODE), IC1.2 (VDD), IC4.5 (VOUT), J3.2, J4.P4 (VDD), Q2.3 (D), R1.2, R1-PINH1.2, R2-PINH1.2, R5.2, R6.2, R7.2, R8.2, R9.2, R10.2, R_BOOT.2, R_CHANGE.2, R_CL1.2, R_RESET.2, TP16.TP, U1.3 (!WP!(IO2)), U1.7 (!HOLD!/!RESET!(IO3)), U1.8 (VCC), U2.2 (3V3), U3.2 (VCC)
32KHZ: R2-PINH1.1, U2.9 (IO1), U3.1 (32KHZ)
DN: D1.4 (I/O2_2), J2.A7, J2.B7
DP: D1.6 (I/O1_2), J2.A6, J2.B6
EPD_3V3: C7.1, EPD_C5.2, J1.15, J1.16, L1.2, Q2.2 (S), TP17.TP
EPD_3V3_C: Q2.1 (G), R_CL1.1, TP13.TP, U2.18 (IO20)
EPD_BUSY: J1.9, TP9.TP, U2.26 (IO3)
EPD_CS: J1.12, TP10.TP, U2.11 (IO10)
EPD_DC: J1.11, TP11.TP, U2.5 (IO5)
EPD_RST: J1.10, TP12.TP, U2.21 (IO23)
FLASH_CS: D6.1, R9.1, U1.1 (!CS), U2.12 (IO11)
GDR: J1.2, Q3.1 (G), R4.2
GND: BOOT_BUTTON.2, C1.2, C1_BAT.2, C1_BAT1.2, C1_BAT2.2, C2.2, C2_BAT.2, C3.-, C4_USB.2, C5.2, C5_USB.2, C6.2, C7.2, C8.2, C9.2, C10.2, C10_SUPERCAP.1, CHANGE_BUTTON.2, C_DELAY.2, D1.2 (GND), D3.1 (K), D6.2, D8.2, D9.2, D10.2, D11.2, D12.2, EPD_C1.1, EPD_C2.1, EPD_C5.1, EPD_C6.1, EPD_C7.1, EPD_C8.1, EPD_C9.1, EPD_C10.1, EPD_C11.1, EPD_C12.1, IC1.3 (GND), IC4.2 (VSS), J1.8, J1.17, J1.MP1, J1.MP2, J2.A1, J2.A12, J2.B1, J2.B12, J2.MP1, J2.MP2, J2.MP3, J2.MP4, J3.1, J4.G1 (GND_1), J4.G2 (GND_2), J4.G3 (GND_3), J4.G4 (GND_4), J4.P6 (VSS), MCP73831.2 (VSS), R1_PWRUSB.1, R2.1, R2-USB.2, R2-USB1.1, R2_BAT.1, R4.1, RESET_BUTTON.2, SENSOR2.1 (GND), SENSOR2.5 (SDO), SENSOR2.7 (GND), SJ1.1, TP4.TP, TP5.TP, U1.4 (GND), U1.9 (EXP), U2.1 (GND), U2.28 (GND), U2.29_1 (GND), U2.29_2 (GND), U2.29_3 (GND), U2.29_4 (GND), U2.29_5 (GND), U2.29_6 (GND), U2.29_7 (GND), U2.29_8 (GND), U2.29_9 (GND), U3.13 (GND), U4.1 (CTG), U4.4 (GND), U4.6 (QSTRT), U4.9 (EP)
GPIO8: R1.1, U2.10 (IO8)
I2C_PW: C1.1, C2.1, R1_PINH.2, R2_PINH.2, SENSOR2.2 (CSB), SENSOR2.6 (VDDIO), SENSOR2.8 (VDD), U2.17 (IO19)
INT_RTC: R1-PINH1.1, TP15.TP, U2.8 (IO0), U3.3 (SQW/!INT)
IO/BOOT: BOOT_BUTTON.4, C6.1, R_BOOT.1, U2.15 (IO9)
IO/CHANGE: C10.1, CHANGE_BUTTON.4, R_CHANGE.1, U2.23 (IO15)
MISO: D11.1, J4.P7 (DAT0), R7.1, TP6.TP, U1.2 (DO(IO1)), U2.27 (IO2)
MOSI: D10.1, J1.14, J4.P3 (CMD), R6.1, TP7.TP, U1.5 (DI(IO0)), U2.7 (IO7)
unnamed: J2.A5, R2-USB1.2
unnamed: J2.B5, R2-USB.1
unnamed: C1_BAT1.1, D2.1 (CATHODE), IC4.1 (VIN), IC4.3 (CE), Q1.2 (S)
unnamed: EPD_C12.2, J1.24
unnamed: C4.1, D3.2 (A), D4.1 (K)
unnamed: MCP73831.5 (PROG), R2_BAT.2
unnamed: CHG_LED.C, R1_BAT.1
unnamed: MCP73831.1 (STAT), R1_BAT.2
unnamed: EPD_C11.2, J1.23
unnamed: EPD_C10.2, J1.22
unnamed: EPD_C9.2, J1.21
unnamed: EPD_C8.2, J1.20
unnamed: EPD_C7.2, J1.19
unnamed: EPD_C6.2, J1.18
unnamed: EPD_C2.2, J1.5
unnamed: EPD_C1.2, J1.4
unnamed: C_DELAY.1, IC1.5 (CT)
unnamed: D7.1 (CATHODE), R_CAPACITOR.1
unnamed: D12.1, R8.1
PREVGH: D5.1 (K)
PREVGL: D4.2 (A)
RESE: J1.3, Q3.2 (S), R3.2
RESE': R2.2, R3.1, SJ1.2
RESET: C5.1, IC1.1 (VOUT), RESET_BUTTON.4, R_RESET.1, U2.3 (EN)
RTC_RST: U2.16 (IO18), U3.4 (!RST)
RX: TP2.TP, U2.24 (RXD0/GPIO17)
SCK: D9.1, J1.13, J4.P5 (CLK), R5.1, TP8.TP, U1.6 (CLK), U2.6 (IO6)
SCL: J3.4, R2_PINH.1, SENSOR2.4 (SCK), U2.20 (IO22), U3.16 (SCL), U4.7 (SCL)
SDA: J3.3, R1_PINH.1, SENSOR2.3 (SDI), U2.19 (IO21), U3.15 (SDA), U4.8 (SDA)
SRC: C4.2, D5.2 (A), L1.1, Q3.3 (D)
SS_SD: J4.P2 (CD/DAT3), U2.4 (IO4)
SS_SD1: D8.1, R10.1
TX: TP1.TP, U2.25 (TXD0/GPIO16)
USB_D+: D1.1 (I/O1_1), U2.14 (IO13)
USB_D-: D1.3 (I/O2_1), U2.13 (IO12)
VBAT: C2_BAT.1, MCP73831.3 (VBAT), Q1.3 (D), TP3.TP, U4.2 (CELL), U4.3 (VDD)
VBUS: C1_BAT.1, C4_USB.1, C5_USB.1, CHG_LED.A, D1.5 (VBUS), D2.2 (ANODE), MCP73831.4 (VIN), PFMF.050.1.2, Q1.1 (G), R1_PWRUSB.2, TP14.TP
VRTC: C8.1, C10_SUPERCAP.2, R_CAPACITOR.2, U3.14 (VBAT)
VUSB: J2.A4, J2.A9, J2.B4, J2.B9, PFMF.050.1.1

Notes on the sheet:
USB C connector & ESD protection
DMG2305UX-7
SD0805S020S1R0
LDO Voltage Regulator
SD Card
Display Type Selector
E-Paper Drive Circuit
Li-Po Battery Charging Controller
ESP32 C6
E-Paper Display Header
EPD Power
Environmental Sensor BME688
Voltage Supervisor + Reset & Boot / IO Button
Battery Charge Level
RTC Module DS3231SN
Test Pads
SPI ESD Protection Lines
External NOR Flash 64MB
Qwiic / Stemma QT

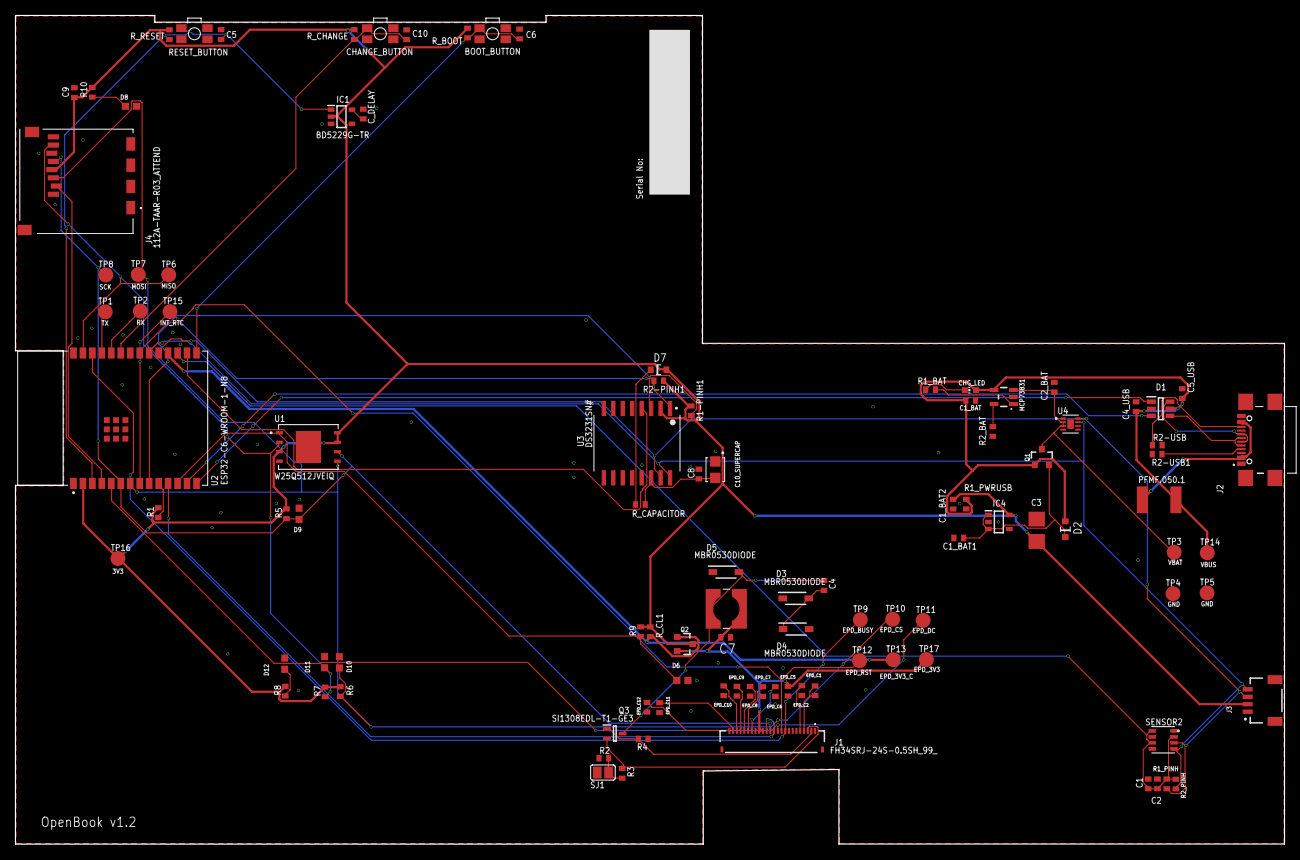
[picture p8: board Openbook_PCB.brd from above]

Board: 2 copper layers, 170.3 x 111.2 mm, 103 parts (0 on the bottom side), 57 nets.

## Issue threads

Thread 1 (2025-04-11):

Schematic Layers Issue

alexbuiac, 2025-04-11:
Liniile de document sunt puse in layer-ul Nets in loc de Info.

Closed 2025-04-15.

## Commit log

2025-04-05 Added brd and sch
    [PCB_Openbook.brd, Schematic_Openbook.sch]
2025-04-06 Added Manufacturing files
    [BOM.csv, PnP.csv]
2025-04-06 Moddified pcb
    [PCB_Openbook.brd]
2025-04-06 Added serial number
    [PCB_Openbook.brd]

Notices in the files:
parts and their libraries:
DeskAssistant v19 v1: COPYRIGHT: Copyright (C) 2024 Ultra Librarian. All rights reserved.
